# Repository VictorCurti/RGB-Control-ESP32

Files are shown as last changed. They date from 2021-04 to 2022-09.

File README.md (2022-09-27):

# RGB Control ESP32 by Victor Curti

# Application

## :page_with_curl: About :

This IOT project aims to control an RGB LED strip (SMD 5050) using Wifi network to communicate the aplication uising HTML5 or Alex voice comande, for this project the ESP32 DevKit V1 was chosen as a controller.

## :selfie: Interfaces :
<table>
  <tr>
    <td>HTML</td>
     <td>BLynk</td>
     
  </tr>
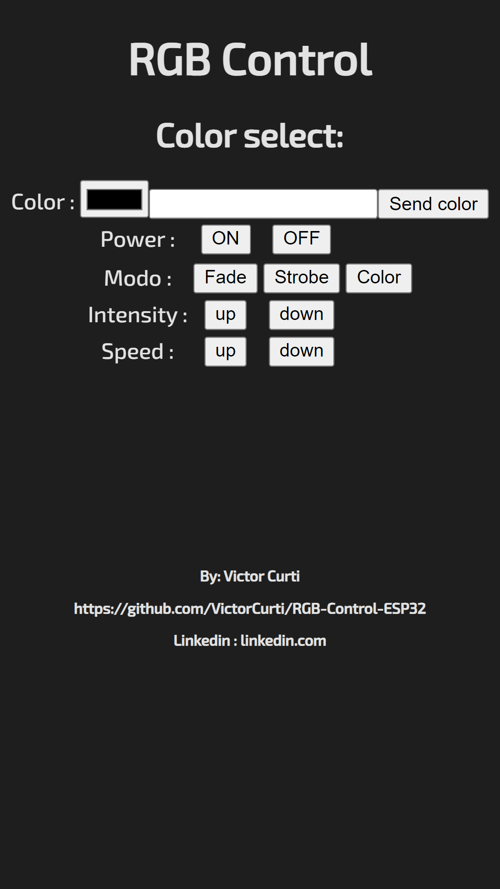
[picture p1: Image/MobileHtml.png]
    <td></td>
 
 </table>
 
Was possible to acess webpage using any browser using as url:
```
  <IP_ADRRES.localhost:8080>

```

# Circuit 

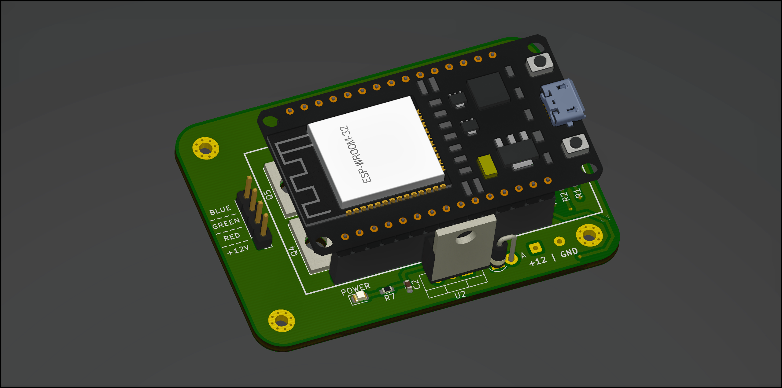
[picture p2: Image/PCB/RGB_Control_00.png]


## Schematic:

Full schematic: https://github.com/VictorCurti/RGB-Control-ESP32/blob/main/Kicad/RGB_Control.pdf

### Driver:

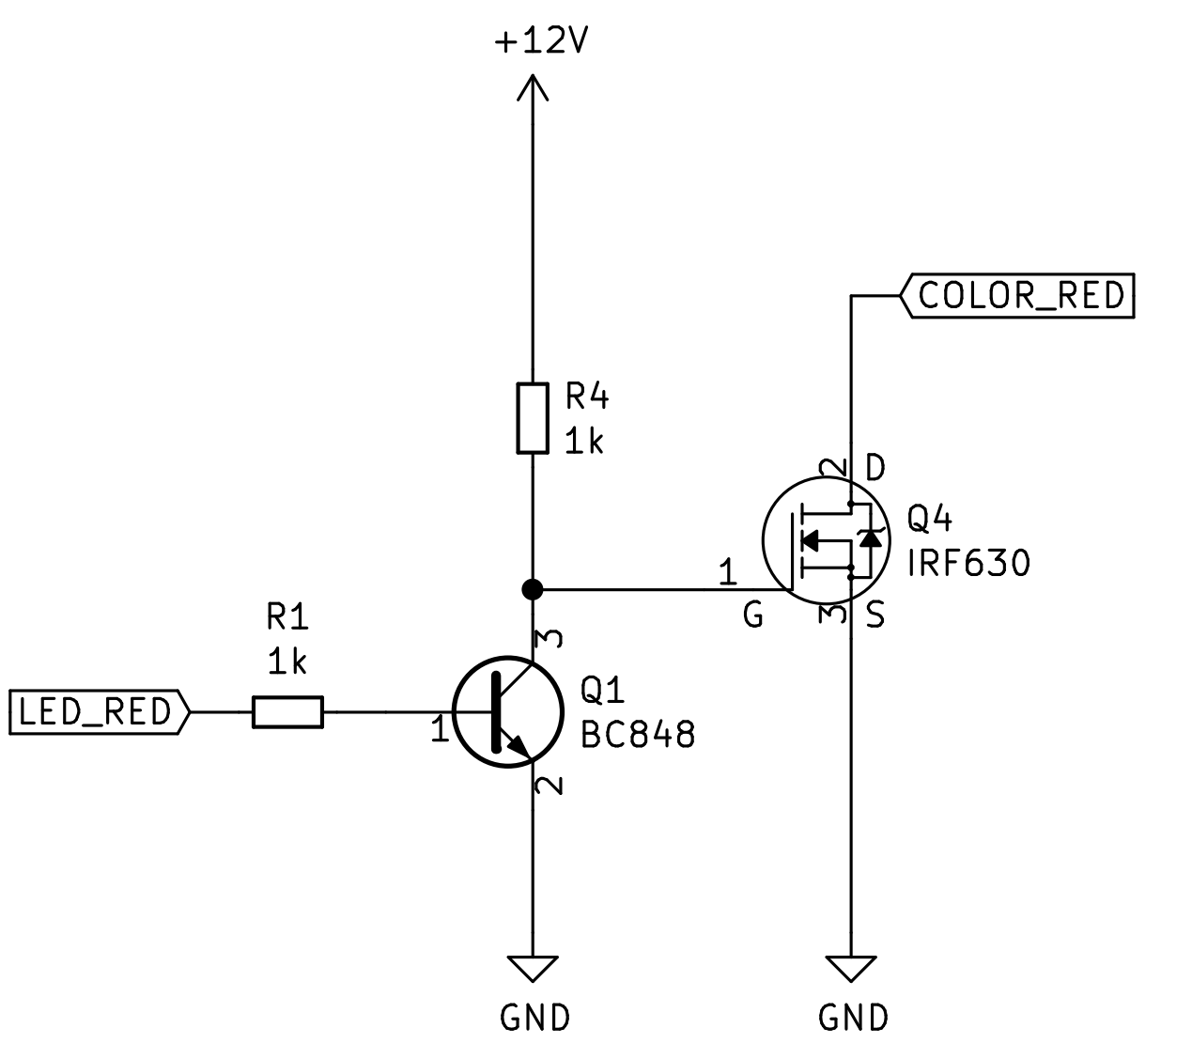
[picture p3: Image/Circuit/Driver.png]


### Controller :

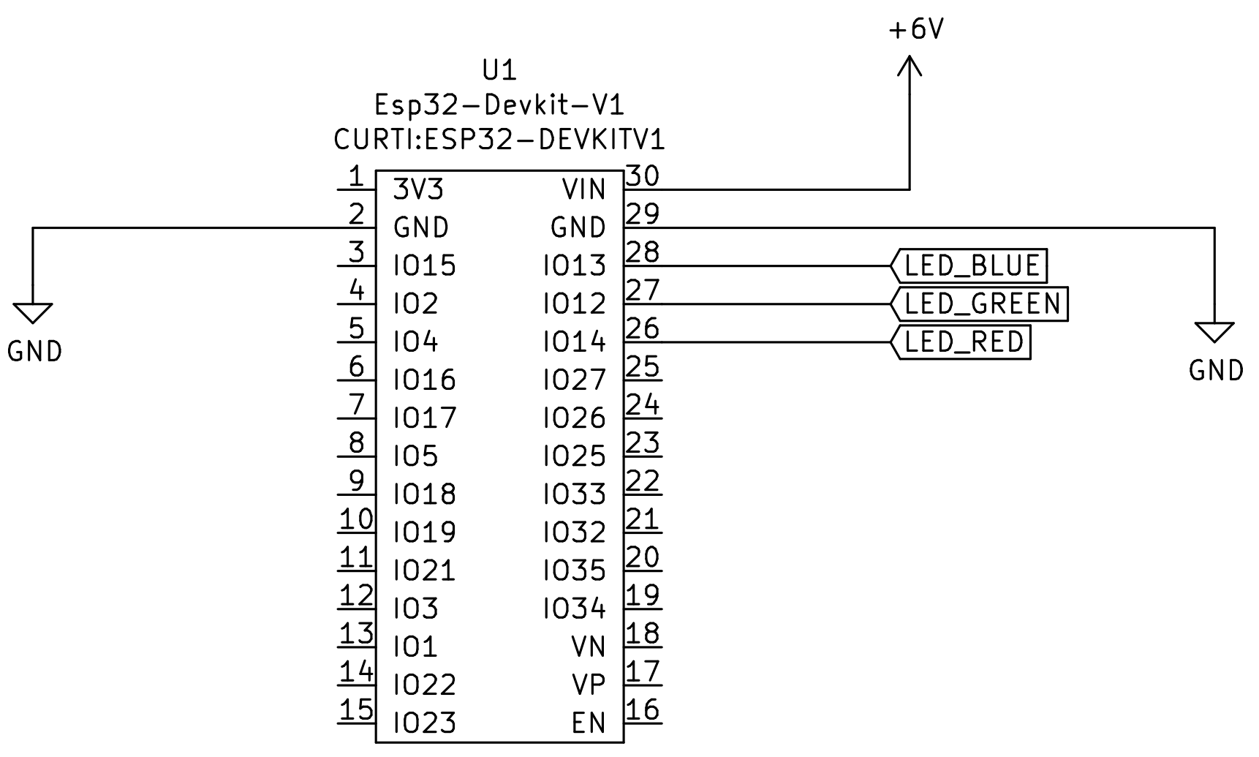
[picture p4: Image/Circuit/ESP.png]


### Supply:

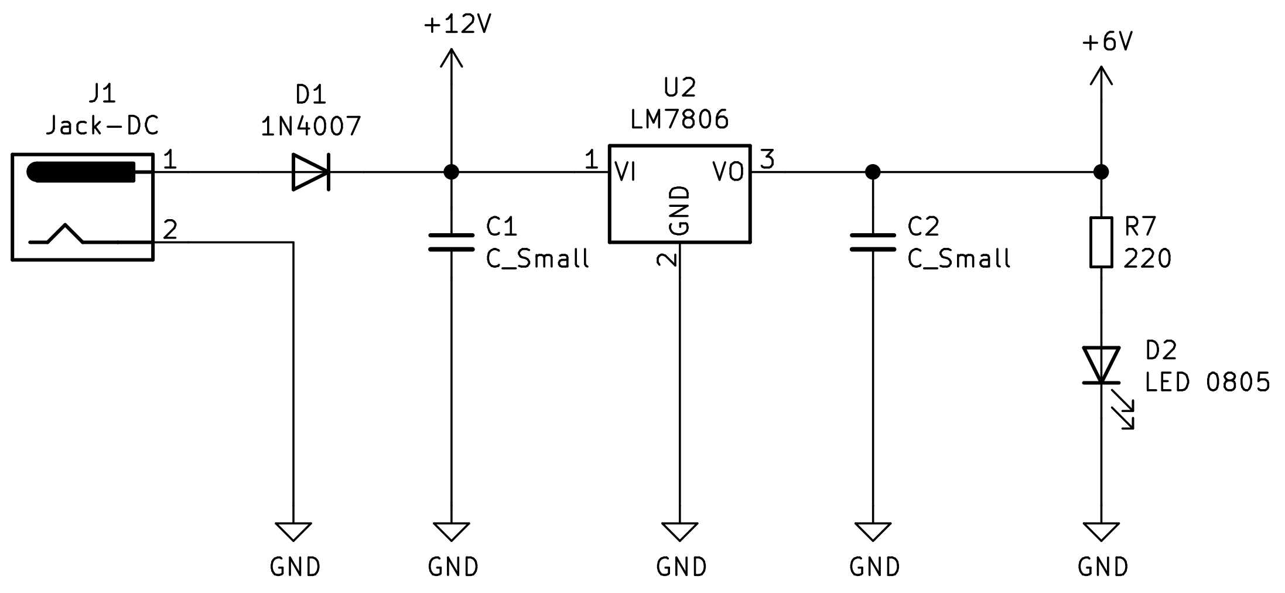
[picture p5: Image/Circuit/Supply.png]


## PCB:

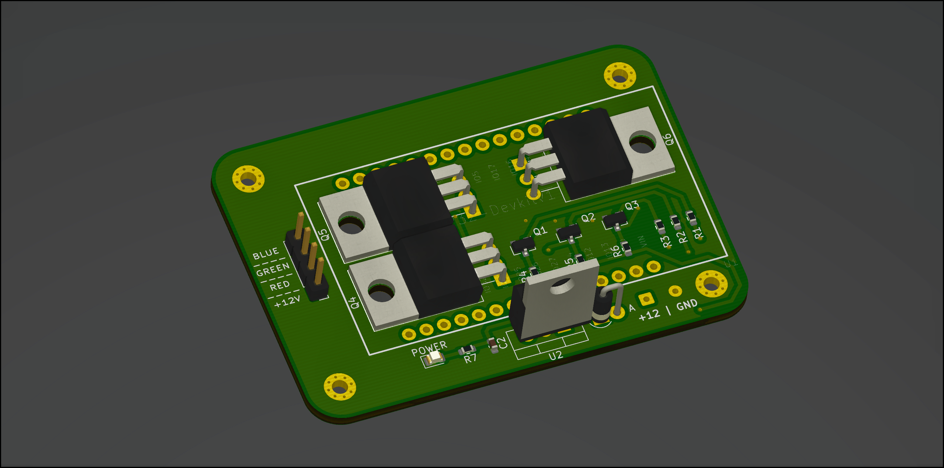
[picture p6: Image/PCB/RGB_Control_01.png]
|   |  |
| --- | --- |
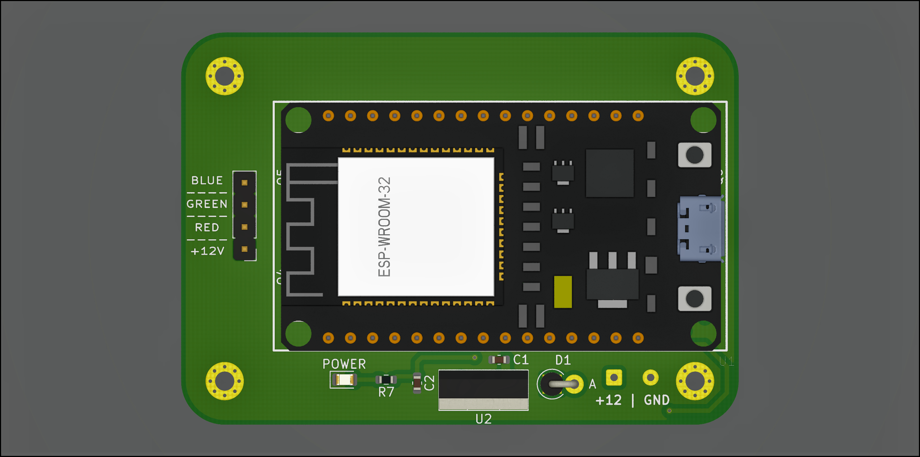
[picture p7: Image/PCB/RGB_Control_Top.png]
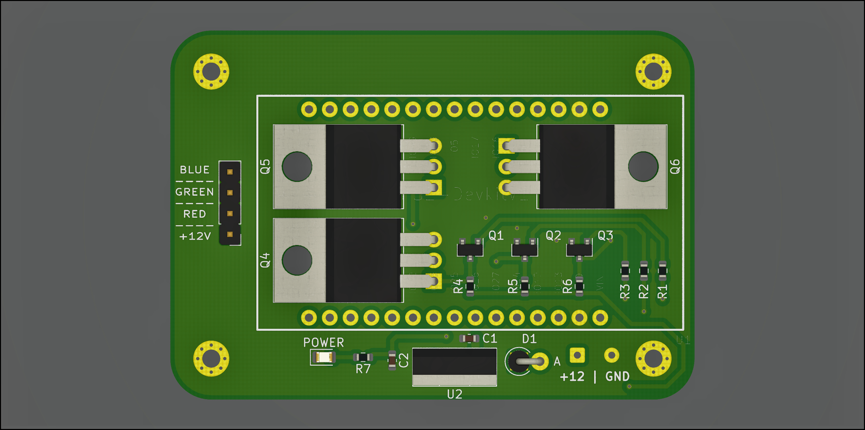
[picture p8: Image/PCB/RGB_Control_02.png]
|   |  |

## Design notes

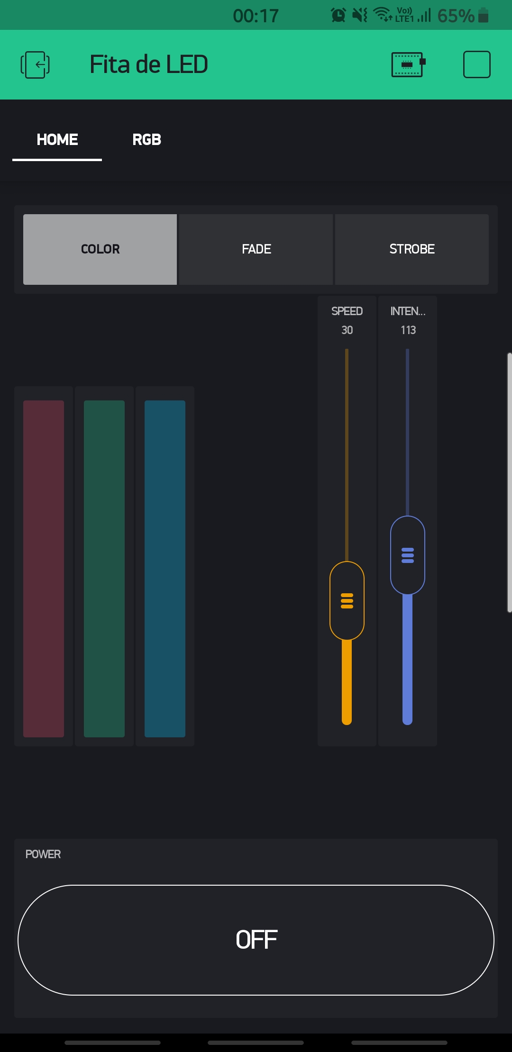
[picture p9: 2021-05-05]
Image/Blynk_Home.jpg

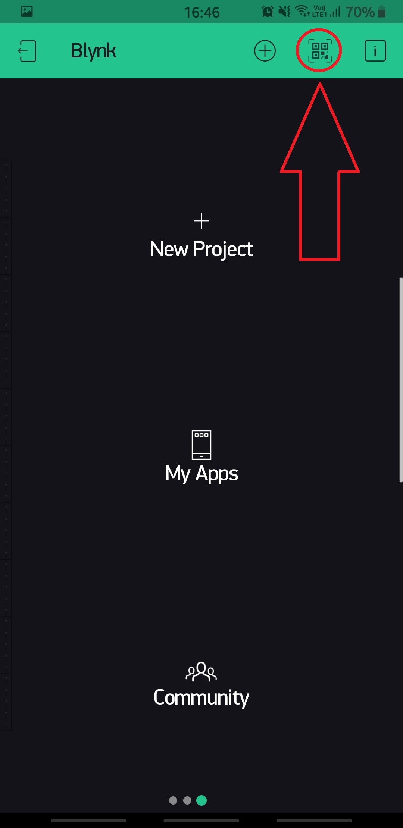
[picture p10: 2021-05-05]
Image/BlynkClone.jpg

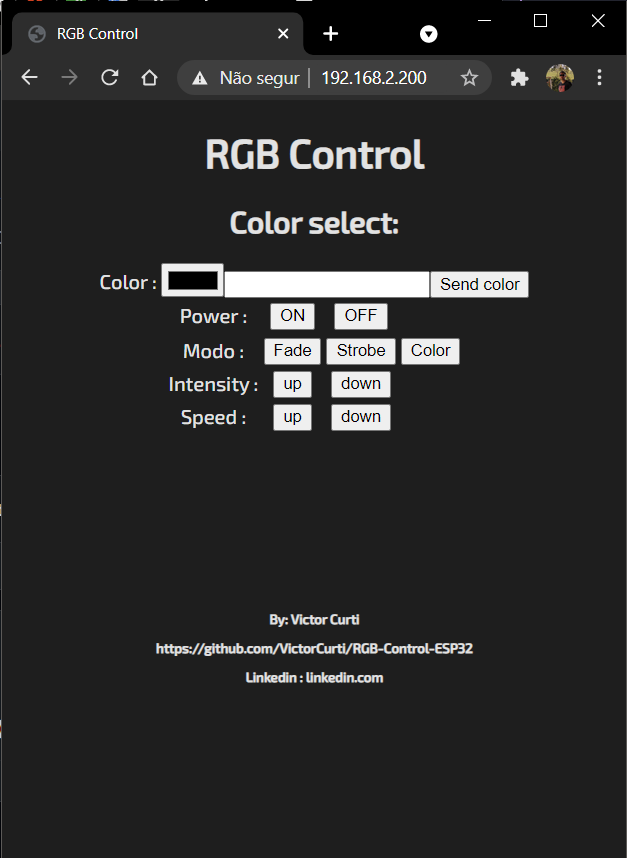
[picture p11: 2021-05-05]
Image/HtmlPage.png

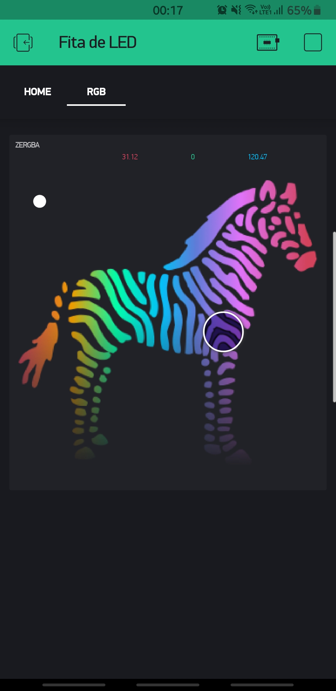
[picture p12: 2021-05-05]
Image/Blynk_RGB.jpg

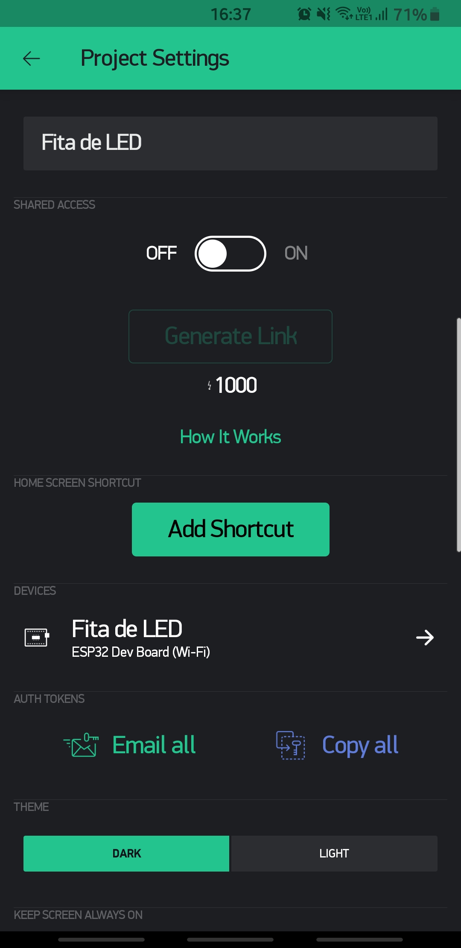
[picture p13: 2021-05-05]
Image/ProjectSettings.jpg

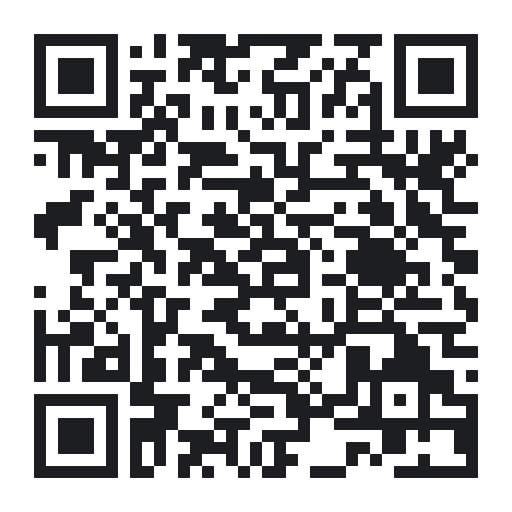
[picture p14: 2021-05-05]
Image/Blynk_Share_Clone.jpeg

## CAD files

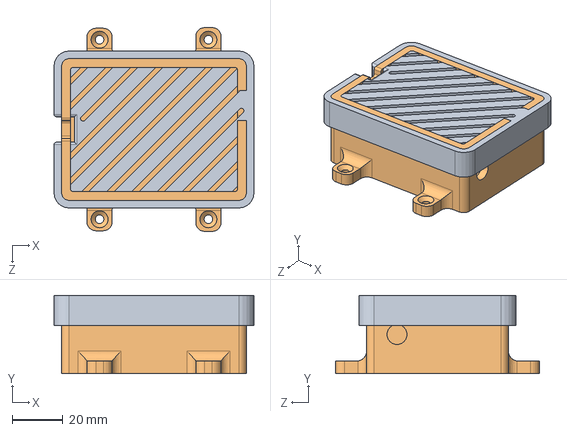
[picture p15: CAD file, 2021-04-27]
Fita RGB Caixa/Mont1.SLDASM
79.0 x 31.0 x 80.5 mm
Fita_RGB
Tampa_RGB

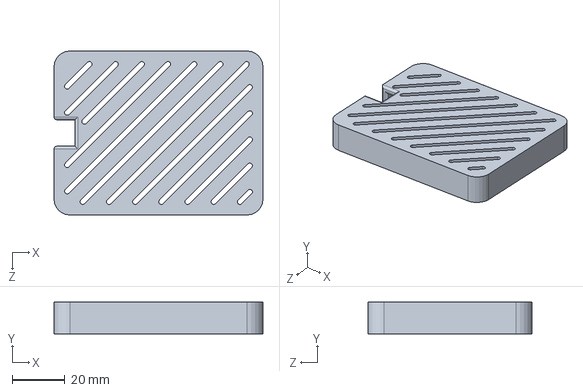
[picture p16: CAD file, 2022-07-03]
Fita RGB Caixa/Tampa_RGB.SLDPRT
79.0 x 12.0 x 62.0 mm

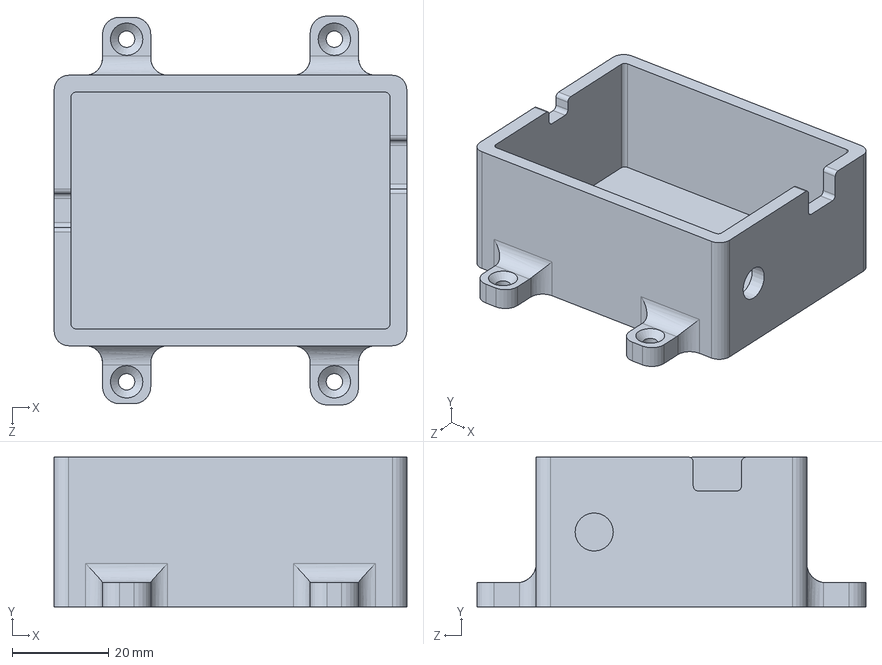
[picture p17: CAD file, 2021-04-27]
Fita RGB Caixa/Fita_RGB.SLDPRT
73.0 x 31.0 x 80.5 mm

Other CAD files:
Fita RGB Caixa/Fita_RGB.STL
Fita RGB Caixa/Tampa_RGB.STL

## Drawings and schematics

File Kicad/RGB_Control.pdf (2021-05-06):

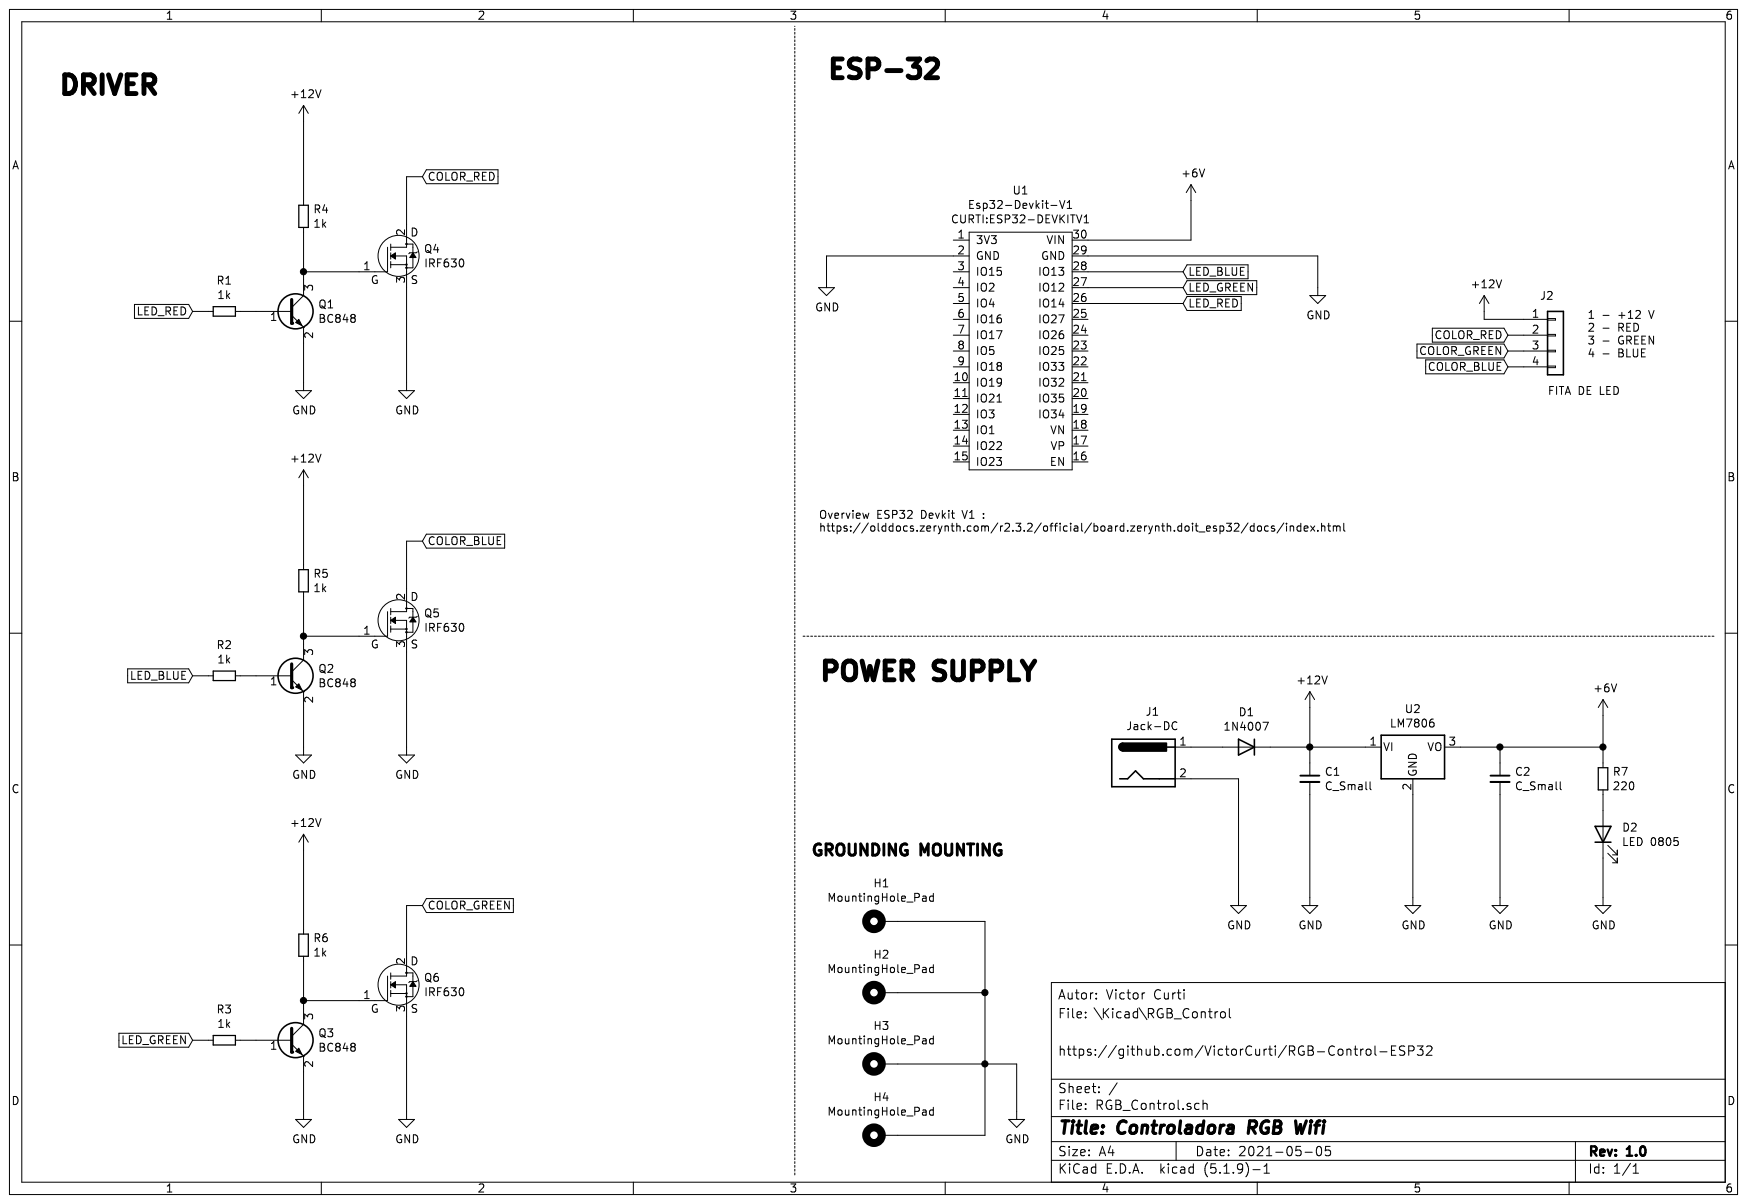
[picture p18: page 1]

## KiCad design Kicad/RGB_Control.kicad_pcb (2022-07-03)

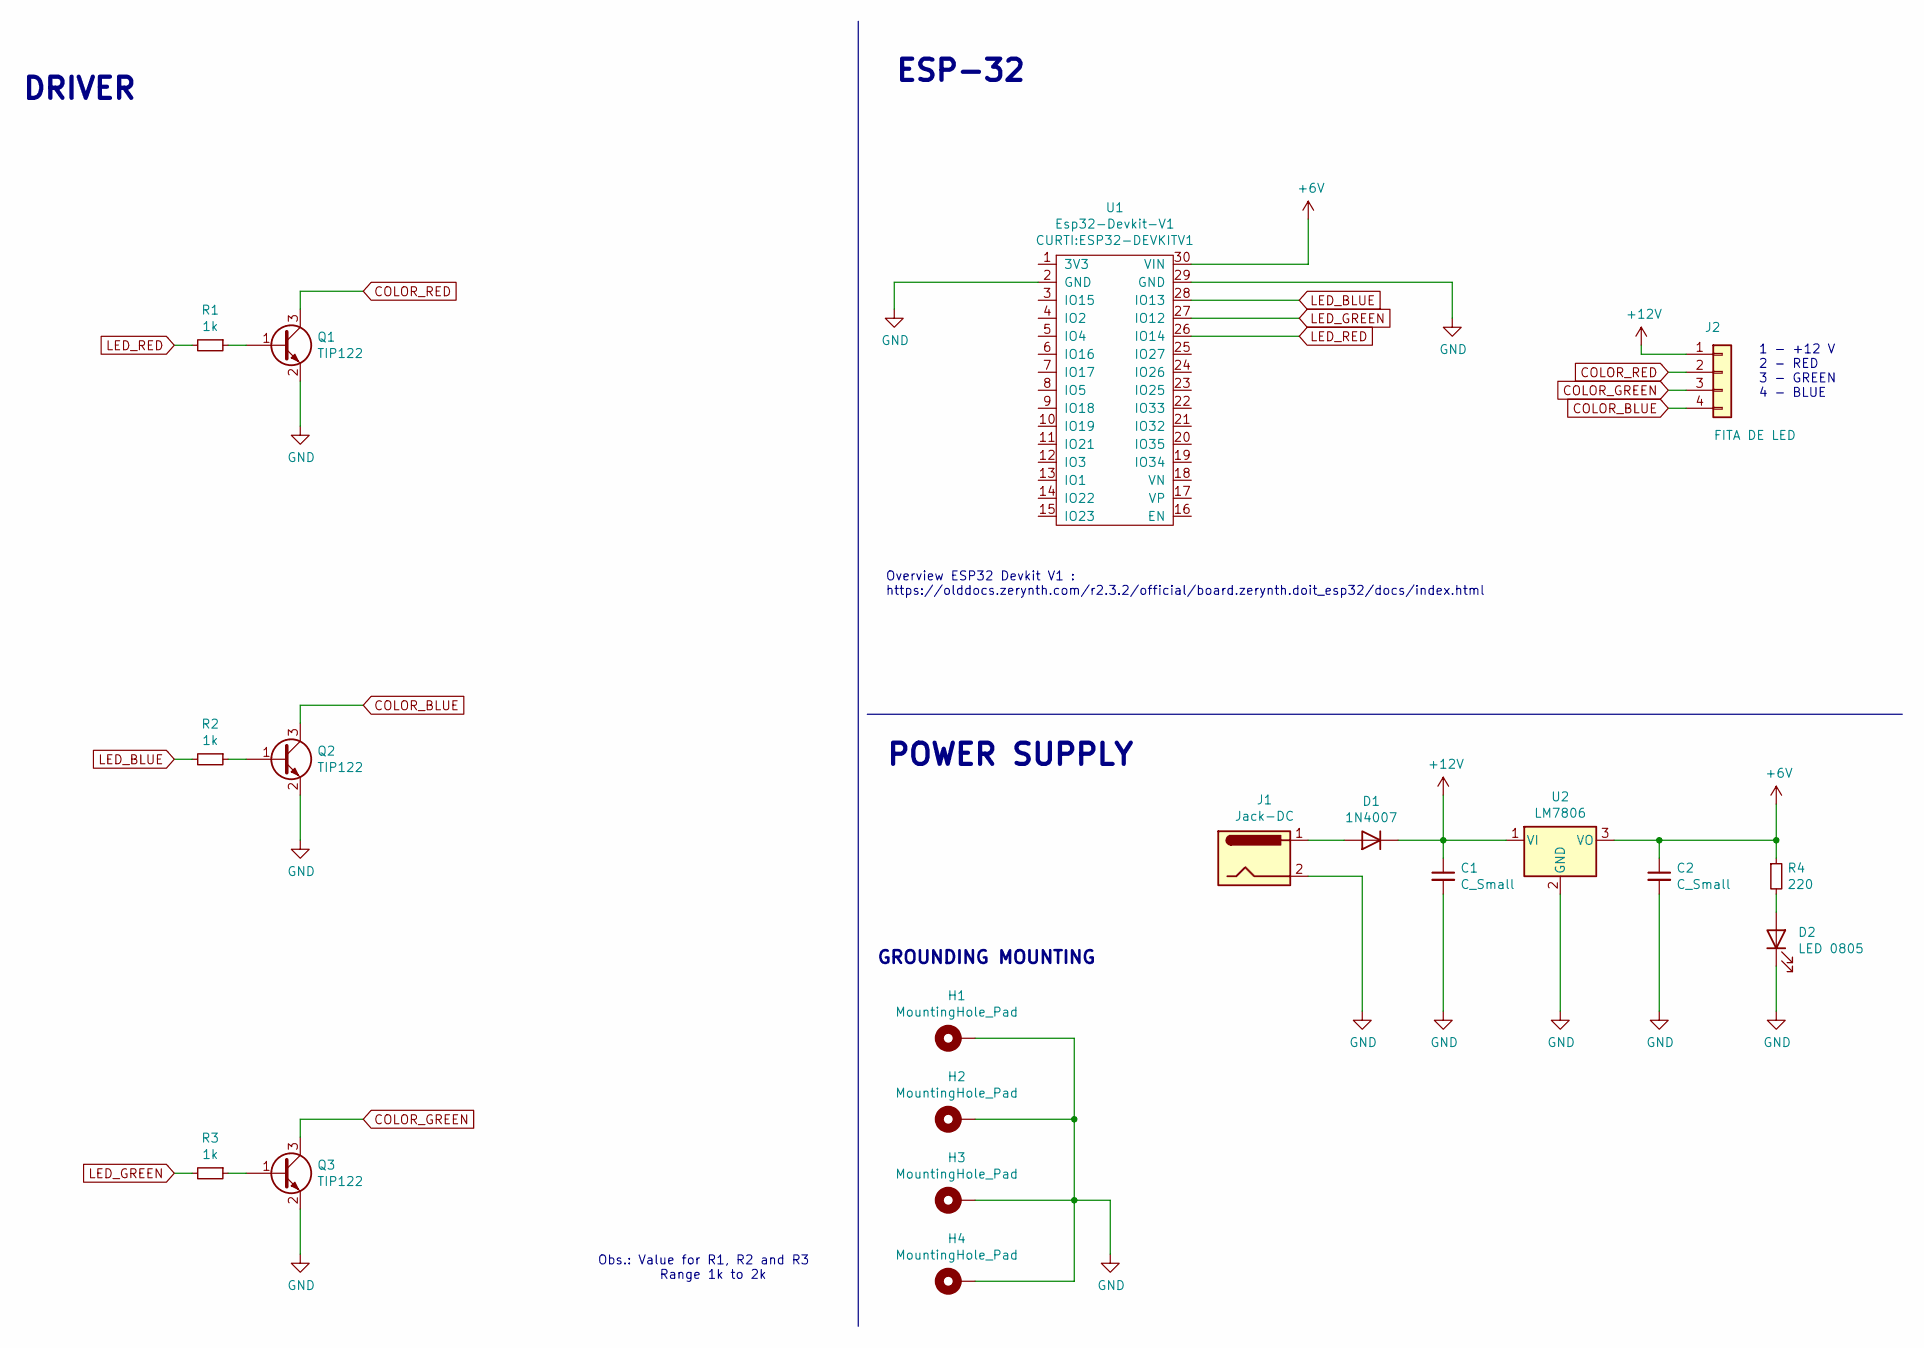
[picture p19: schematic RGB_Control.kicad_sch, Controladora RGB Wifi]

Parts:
C1, C2: C_Small; C_Rect_L4.6mm_W2.0mm_P2.50mm_MKS02_FKP02
D1: 1N4007; D_A-405_P2.54mm_Vertical_AnodeUp
D2: LED 0805; LED_D3.0mm
H1, H2, H3, H4: MountingHole_Pad; MountingHole_2.2mm_M2_Pad_Via
J1: Jack-DC; SolderWire-0.25sqmm_1x02_P4.2mm_D0.65mm_OD1.7mm
J2: FITA DE LED; PinHeader_1x04_P2.54mm_Vertical
Q1, Q2, Q3: TIP122; TO-220-3_Horizontal_TabDown
R1, R2, R3: 1k; R_Axial_DIN0207_L6.3mm_D2.5mm_P7.62mm_Horizontal
R4: 220; R_Axial_DIN0207_L6.3mm_D2.5mm_P2.54mm_Vertical
U1: Esp32-Devkit-V1; ESP32-DEVKITV1
U2: LM7806; TO-220-3_Vertical

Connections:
+6V: C2.1, R4.1, U1.30 (VIN), U2.3 (VO); also elsewhere on the board
+12V: C1.1, D1.1 (K), J2.1, U2.1 (VI)
COLOR_BLUE: J2.4, Q2.3 (C)
COLOR_GREEN: J2.3, Q3.3 (C)
COLOR_RED: J2.2, Q1.3 (C)
GND: C1.2, C2.2, D2.1 (K), H1.1, H2.1, H3.1, H4.1, J1.2, Q1.2 (E), Q2.2 (E), Q3.2 (E), U1.2 (GND), U1.29 (GND), U2.2 (GND)
LED_BLUE: R2.2, U1.28 (IO13)
LED_GREEN: R3.2, U1.27 (IO12)
LED_RED: R1.2, U1.26 (IO14)
unnamed: D1.2 (A), J1.1
unnamed 10: D2.2 (A), R4.2; also elsewhere on the board
unnamed: Q1.1 (B), R1.1
unnamed: Q2.1 (B), R2.1
unnamed: Q3.1 (B), R3.1

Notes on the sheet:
Overview ESP32 Devkit V1 : https://olddocs.zerynth.com/r2.3.2/official/board.zerynth.doit_esp32/docs/index.html
DRIVER
Obs.: Value for R1, R2 and R3 Range 1k to 2k
GROUNDING MOUNTING
ESP-32
POWER SUPPLY
1 - +12 V 2 - RED 3 - GREEN 4 - BLUE

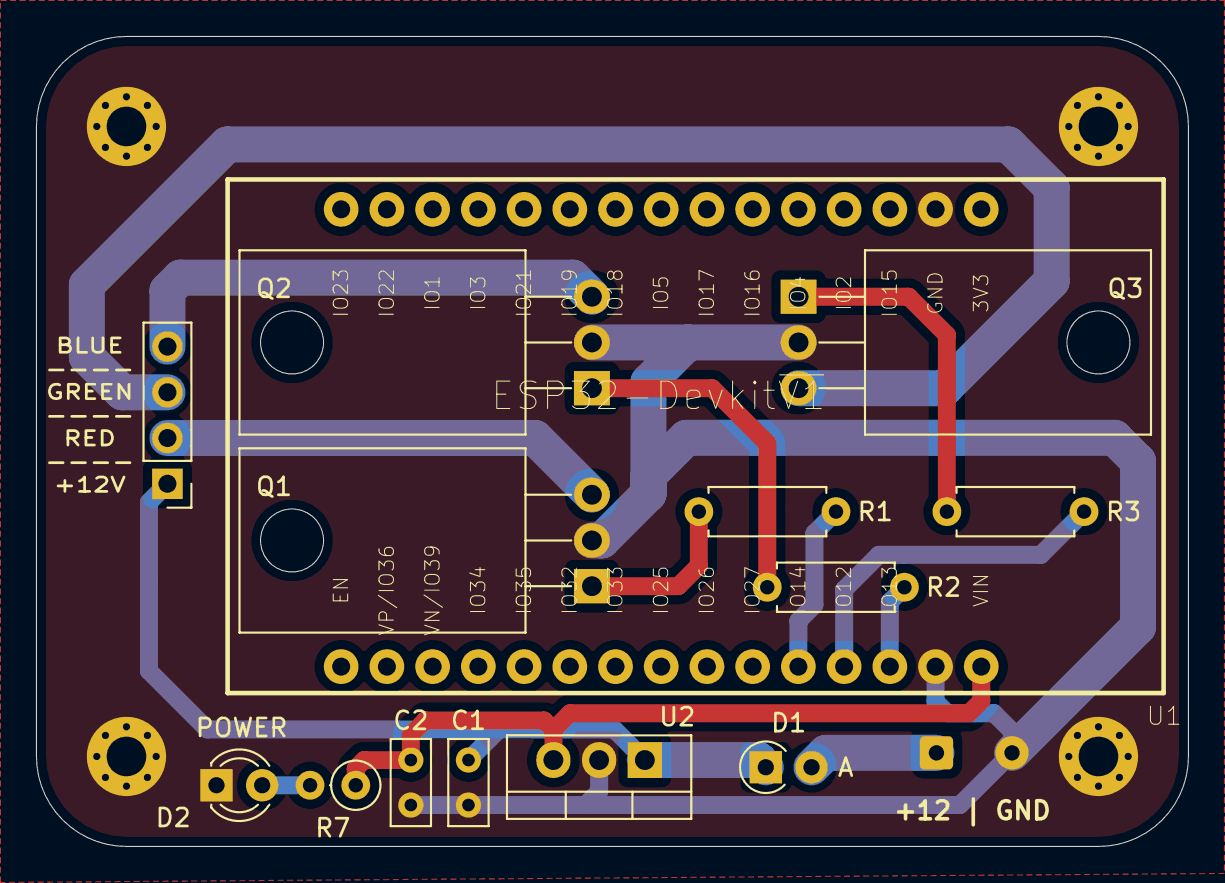
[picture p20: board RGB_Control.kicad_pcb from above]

Board: 2 copper layers, 64.0 x 45.0 mm, 19 parts (0 on the bottom side), 14 nets.

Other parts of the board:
R7: 220; R_Axial_DIN0207_L6.3mm_D2.5mm_P2.54mm_Vertical

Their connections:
+6V: R7.1; also elsewhere on the board
unnamed 10: R7.2; also elsewhere on the board

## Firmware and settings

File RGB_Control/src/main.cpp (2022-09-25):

//================================================================
//
//  Author: Victor Curti        (May 2021)
//  Board ESP32 - Devkit V1
//  RGB Control with Alexa + OTA
//
//================================================================

#define ESPALEXA_ASYNC // Fix Webserver Espalexa v2.3.0

#include <Arduino.h>           //Vscode library for arduino
#include <AsyncElegantOTA.h>   //OTA
#include <AsyncTCP.h>          //HTML page
#include <ESPAsyncWebServer.h> //HTML
#include <map>                 //Map library (Dictionary HEX color to RGB)
#include <ESPmDNS.h>           //DNS (NAME.local)
#include <Espalexa.h>

AsyncWebServer server1(8080); // HTML web page port

// Maping pins
#define LED 2        // Onboard led
#define LED_RED 14   // Pin Red color
#define LED_GREEN 12 // Pin green color
#define LED_BLUE 13  // Pin blue color

// PWM Configuration
#define ChannelPwmRed 0   // PWM channel from red color
#define ChannelPwmGreen 1 // PWM channel from green color
#define ChannelPwmBlue 2  // PWM channel from blue color
#define FrequencyPwm 60   // Frequency of PWM[Hz]

//================================================================
//                         Global variables
//================================================================
// Delay time
int FadeDelay;
int StrobeDelay;

// ------------------------
int intensity = 128;
int Fade_Red, Fade_Green, Fade_Blue, Fade_Step, Temp;
long OldTime = -1;

// Tag comunication (LocalIp/get?PARAM_INPUT=XXXX)
const char *PARAM_INPUT_1 = "color";
const char *PARAM_INPUT_2 = "power";
const char *PARAM_INPUT_3 = "mode";
const char *PARAM_INPUT_4 = "intensity";
const char *PARAM_INPUT_5 = "speed";

// States
String Power = "OFF", Mode = "NULL", Color = "#000000";

struct RGB_Color
{
  int Red = 0; // RGB code color
  // int PwmRed = map(Red, 0, 255, 0, 1023);     //Conversion RGB (8 bits) to PWM (10 bits)
  int Green = 0; // RGB code color
  // int PwmGreen = map(Green, 0, 255, 0, 1023); //Conversion RGB (8 bits) to PWM (10 bits)
  int Blue = 0; // RGB code color
  // int PwmBlue = map(Blue, 0, 255, 0, 1023);   //Conversion RGB (8 bits) to PWM (10 bits)
} Cor_RGB;

// Alexa Esp
Espalexa espalexa;

/**************************/
std::map<char, int> HexTable;

//================================================================
//                         Functions
//================================================================

void Init_Map();
void Hex2RGB(String);
void SerialDebug();
void PWM_RGB();
void WifiConect(bool);

// Esp Alexa
void colorLightChanged(uint8_t brightness, uint32_t rgb);
//================================================================
//                         Local libraries
//================================================================

#include "HTML_Index.hpp"
#include "Credentials/credentials.hpp"

// credentials.hpp
/*
    // Your WiFi credentials.
    // Set password to "" for open networks.
    char ssid[] = "Name";
    char pass[] = "Password";
*/

//==============================================================================================
void setup()
{

  // Create a dictionary HEX color to RGB color
  Init_Map();

  // Configuration GPIO station
  pinMode(LED_RED, OUTPUT);
  pinMode(LED_GREEN, OUTPUT);
  pinMode(LED_BLUE, OUTPUT);
  pinMode(LED, OUTPUT);

  // Start pins
  digitalWrite(LED_RED, HIGH);
  digitalWrite(LED_GREEN, HIGH);
  digitalWrite(LED_BLUE, HIGH);
  digitalWrite(LED, LOW);

  // PWM Initialize
  ledcSetup(ChannelPwmRed, FrequencyPwm, 8);
  ledcSetup(ChannelPwmGreen, FrequencyPwm, 8);
  ledcSetup(ChannelPwmBlue, FrequencyPwm, 8);

  ledcWrite(ChannelPwmRed, 256);
  ledcWrite(ChannelPwmGreen, 256);
  ledcWrite(ChannelPwmBlue, 256);

  // Channel PWM configuration
  ledcAttachPin(LED_RED, ChannelPwmRed);
  ledcAttachPin(LED_GREEN, ChannelPwmGreen);
  ledcAttachPin(LED_BLUE, ChannelPwmBlue);

  // Conect ESP to Wifi
  Serial.begin(9600);
  WifiConect(true);

  // Change ip address to name rgbcontrol
  // ping rgbcontrol.local
  if (!MDNS.begin("rgb_control"))
  {
#ifdef DEBUG
    Serial.println("Error starting mDNS");
#endif
    return;
  }

  // If can`t conect to wifi, reboot device
  if (WiFi.waitForConnectResult() != WL_CONNECTED)
  {
#ifdef DEBUG
    Serial.println("WiFi Failed!");
#endif
    return;
  }

#ifdef DEBUG
  Serial.println("OTA HTTP server on");
#endif

#ifdef DEBUG
  Serial.print("IP Address: ");
  Serial.println(WiFi.localIP());
  Serial.println("\n\n\n");
#endif

  // AsyncElegantOTA.begin(&server); // Start ElegantOTA without password
  AsyncElegantOTA.begin(&server1, "admin", "agoravai");

  // Esp Alexa
  espalexa.addDevice("Fita", colorLightChanged); // simplest definition, default state off
  espalexa.begin();

  // Create Async WebServer (File: HTML_Index.hpp)
  InitializeServer();

  digitalWrite(LED, HIGH);
  delay(500);
  digitalWrite(LED, LOW);
}

void loop()
{

#ifdef DEBUG
  SerialDebug();
#endif
  if (WiFi.status() != WL_CONNECTED)
  {
    digitalWrite(LED, HIGH);
    // WifiConect(false);
    WiFi.disconnect();
    delay(500);
    WiFi.reconnect();
  }
  espalexa.loop();
  PWM_RGB();
  delay(1);
  digitalWrite(LED, LOW);
}

void WifiConect(bool stage)
{
  bool aux = false;
  WiFi.disconnect();
  WiFi.mode(WIFI_STA);
  WiFi.begin(ssid, pass);

  if (stage)
  {
    ledcWrite(ChannelPwmGreen, (128));
  }

#ifdef DEBUG
  Serial.println("Connecting to WiFi..");
#endif

  while (WiFi.status() != WL_CONNECTED)
  {
    delay(250);

    if (stage)
    {
      if (aux)
      {
        ledcWrite(ChannelPwmGreen, 256);
        aux = false;
      }
      else
      {
        ledcWrite(ChannelPwmGreen, 128);
        aux = true;
      }
    }

#ifdef DEBUG
    Serial.print(".");
#endif
  }

#ifdef DEBUG
  Serial.println("Connected to the WiFi network");
#endif

  PWM_RGB();

  WiFi.setHostname("rgb-control"); // Name on router
}

// Dictionary hexdecimal to decimal
void Init_Map()
{
  HexTable['0'] = 0;
  HexTable['1'] = 1;
  HexTable['2'] = 2;
  HexTable['3'] = 3;
  HexTable['4'] = 4;
  HexTable['5'] = 5;
  HexTable['6'] = 6;
  HexTable['7'] = 7;
  HexTable['8'] = 8;
  HexTable['9'] = 9;
  HexTable['a'] = 10;
  HexTable['b'] = 11;
  HexTable['c'] = 12;
  HexTable['d'] = 13;
  HexTable['e'] = 14;
  HexTable['f'] = 15;
}

void Hex2RGB(String HEX_COLOR)
{
  Cor_RGB.Red = (HexTable[HEX_COLOR[1]] * 16 + HexTable[HEX_COLOR[2]]);
  Cor_RGB.Green = (HexTable[HEX_COLOR[3]] * 16 + HexTable[HEX_COLOR[4]]);
  Cor_RGB.Blue = (HexTable[HEX_COLOR[5]] * 16 + HexTable[HEX_COLOR[6]]);
}

void SerialDebug()
{
  if ((OldTime == -1) || ((millis() - OldTime) >= 1000))
  {
    OldTime = millis();
    Serial.println("Mensagens:");
    Serial.print("\tPower: ");
    Serial.println(Power);
    Serial.print("\tColor: ");
    Serial.println(Color);
    Serial.print("\t\tRED: ");
    Serial.println(Cor_RGB.Red);
    Serial.print("\t\tGREEN: ");
    Serial.println(Cor_RGB.Green);
    Serial.print("\t\tBLUE: ");
    Serial.println(Cor_RGB.Blue);

    Serial.print("\t\tFADE - RED: ");
    Serial.println(Fade_Red);
    Serial.print("\t\tFADE - GREEN: ");
    Serial.println(Fade_Green);
    Serial.print("\t\tFADE - BLUE: ");
    Serial.println(Fade_Blue);
    Serial.print("\t\tFADE - STEP: ");
    Serial.println(Fade_Step);

    Serial.print("\tMode: ");
    Serial.println(Mode);
    Serial.print("\tIntensity: ");
    Serial.println(intensity);
  }
}

void PWM_RGB()
{
  if (Power == "ON" && Mode == "Color")
  {
    ledcWrite(ChannelPwmRed, (256 - Cor_RGB.Red));
    ledcWrite(ChannelPwmGreen, (256 - Cor_RGB.Green));
    ledcWrite(ChannelPwmBlue, (256 - Cor_RGB.Blue));

    delay(100);
  }
  else if (Power == "ON" && Mode == "Fade")
  {
    ledcWrite(ChannelPwmRed, (256 - Fade_Red));
    ledcWrite(ChannelPwmGreen, (256 - Fade_Green));
    ledcWrite(ChannelPwmBlue, (256 - Fade_Blue));

    if (Fade_Step == 0 && Fade_Red < 256)
      Fade_Red++;
    else if (Fade_Step == 1 && Fade_Green < 256)
      Fade_Green++;
    else if (Fade_Step == 2 && Fade_Blue < 256)
      Fade_Blue++;
    else if (Fade_Step == 3 && Fade_Red > 0)
      Fade_Red--;
    else if (Fade_Step == 4 && Fade_Green > 0)
      Fade_Green--;
    else if (Fade_Step == 5 && Fade_Blue > 0)
      Fade_Blue--;

    if (Fade_Red == 256 && Fade_Step == 0)
      Fade_Step++;
    else if (Fade_Green == 256 && Fade_Step == 1)
      Fade_Step++;
    else if (Fade_Blue == 256 && Fade_Step == 2)
      Fade_Step++;
    else if (Fade_Red == 0 && Fade_Step == 3)
      Fade_Step++;
    else if (Fade_Green == 0 && Fade_Step == 4)
      Fade_Step++;
    else if (Fade_Blue == 0 && Fade_Step == 5)
      Fade_Step = 0;

    delay(FadeDelay);
  }
  else if (Power == "ON" && Mode == "Strobe")
  {

    ledcWrite(ChannelPwmRed, 256);
    ledcWrite(ChannelPwmGreen, 256);
    ledcWrite(ChannelPwmBlue, 256);

    switch (random(0, 7))
    {
    case 0:
      Temp = random(30, intensity);
      ledcWrite(ChannelPwmRed, (256 - Temp));
      break;
    case 1:
      Temp = random(30, intensity);
      ledcWrite(ChannelPwmGreen, (256 - Temp));
      break;
    case 2:
      Temp = random(30, intensity);
      ledcWrite(ChannelPwmBlue, (256 - Temp));
      break;
    case 3:
      Temp = random(30, intensity);
      ledcWrite(ChannelPwmRed, (256 - Temp));
      Temp = random(30, intensity);
      ledcWrite(ChannelPwmGreen, (256 - Temp));
      break;
    case 4:
      Temp = random(30, intensity);
      ledcWrite(ChannelPwmRed, (256 - Temp));
      Temp = random(30, intensity);
      ledcWrite(ChannelPwmBlue, (256 - Temp));
      break;
    case 5:
      Temp = random(30, intensity);
      ledcWrite(ChannelPwmGreen, (256 - Temp));
      Temp = random(30, intensity);
      ledcWrite(ChannelPwmBlue, (256 - Temp));
      break;
    case 6:
      Temp = random(30, intensity);
      ledcWrite(ChannelPwmRed, (256 - Temp));
      Temp = random(30, intensity);
      ledcWrite(ChannelPwmGreen, (256 - Temp));
      Temp = random(30, intensity);
      ledcWrite(ChannelPwmBlue, (256 - Temp));
      break;
    default:
      ledcWrite(ChannelPwmRed, 256);
      ledcWrite(ChannelPwmGreen, 256);
      ledcWrite(ChannelPwmBlue, 256);
    }

    delay(StrobeDelay * 10);
  }
  else if (Power == "OFF")
  {
    ledcWrite(ChannelPwmRed, 256);
    ledcWrite(ChannelPwmGreen, 256);
    ledcWrite(ChannelPwmBlue, 256);
  }
}
/*Esp with Alexa
 */
void colorLightChanged(uint8_t brightness, uint32_t rgb)
{
  // do what you need to do here, for example control RGB LED strip

  if (brightness == 0)
  {
    Power = "OFF";
  }
  else
  {
    Mode = "Color";
    Power = "ON";
  }

  // Get Color from Alexa
  Cor_RGB.Red = ((rgb >> 16) & 0xFF);
  Cor_RGB.Green = ((rgb >> 8) & 0xFF);
  Cor_RGB.Blue = (rgb & 0xFF);

  uint8_t brilho = brightness;
#ifdef DEBUG
  Serial.println("\n\n-Brilho:");
  Serial.println(brilho);
#endif
  brilho = map(brilho,
               1, 255,
               0, 100);
#ifdef DEBUG
  Serial.println(brilho);
#endif
  // Applay

  Cor_RGB.Red = (int)(Cor_RGB.Red * (brilho / 100.0));
  Cor_RGB.Green = (int)(Cor_RGB.Green * (brilho / 100.0));
  Cor_RGB.Blue = (int)(Cor_RGB.Blue * (brilho / 100.0));

#ifdef DEBUG
  Serial.print("Brightness: ");
  Serial.print(brightness);
  Serial.println("RGB[EspAlexa]: ");

  Serial.print(", Red: ");
  Serial.print((rgb >> 16) & 0xFF); // get red component
  Serial.print(", Green: ");
  Serial.print((rgb >> 8) & 0xFF); // get green
  Serial.print(", Blue: ");
  Serial.println(rgb & 0xFF); // get blue
#endif
}

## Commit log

2021-04-27 commit message
    [Fita_RGB.SLDPRT, Fita_RGB.STL, Mont1.SLDASM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]
2021-05-06 Kicad PCB
    [RGB_Control.kicad_pcb, RGB_Control.sch]
2021-05-07 Schematic Imagens
2021-05-27 Circuit V2 - BJT
    [RGB_Control.kicad_pcb, RGB_Control.sch]
2022-07-02 fix Espalexa.h and ESPAsyncWebServer.h
    [RGB_Control.kicad_sch]
2022-07-03 Fix & update
    [Tampa_RGB.SLDPRT, Tampa_RGB.STL]
